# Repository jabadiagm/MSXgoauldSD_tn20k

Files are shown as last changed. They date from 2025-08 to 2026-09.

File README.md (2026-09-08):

# MSXgoauldSD_tn20k
MSX Goa'uld board with Tang Nano 20k and SD support

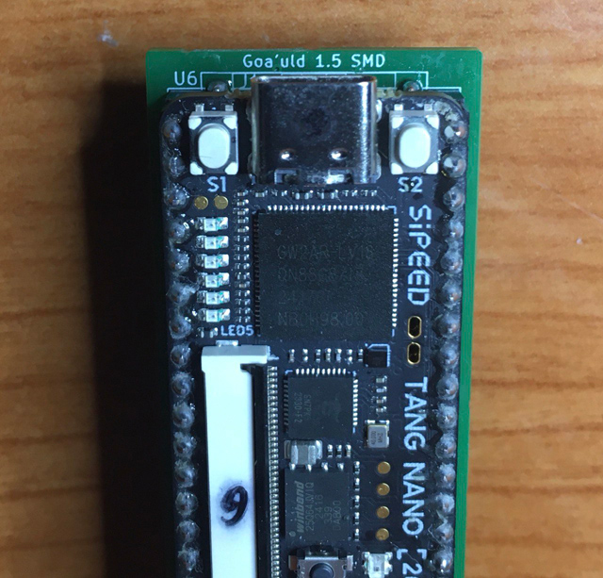
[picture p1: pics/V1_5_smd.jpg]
V1.5_SMD


MSX2+ engine in Z80 socket. It turns one MSX into an MSX2+ by replacing Z80 processor. FPGA in board contains: 
* Z80
* V9958 with hdmi output
* MSX2+ BIOS
* SD Card support + Nextor 2.1
* 4MB mapper
* 2MB megaram SCC
* RTC
* PSG
* OPLL
* Kanji Level 1 & 2
* Wifi support using ESP (experimental)

**For 240p analog video support for consumer CRTs watch DirectVideo branch**

## Boards

Old boards V1.4 and V4.1 are compatible with Goa'uld SD. V3 is not supported, owners of V3 should use Goa'uld standard firmware (0.80).

New pcb V1.5 is same as 1.4, optimized for online PCB assembly. See [Assembly guide](/pcba/pcba.md)

## Slot map

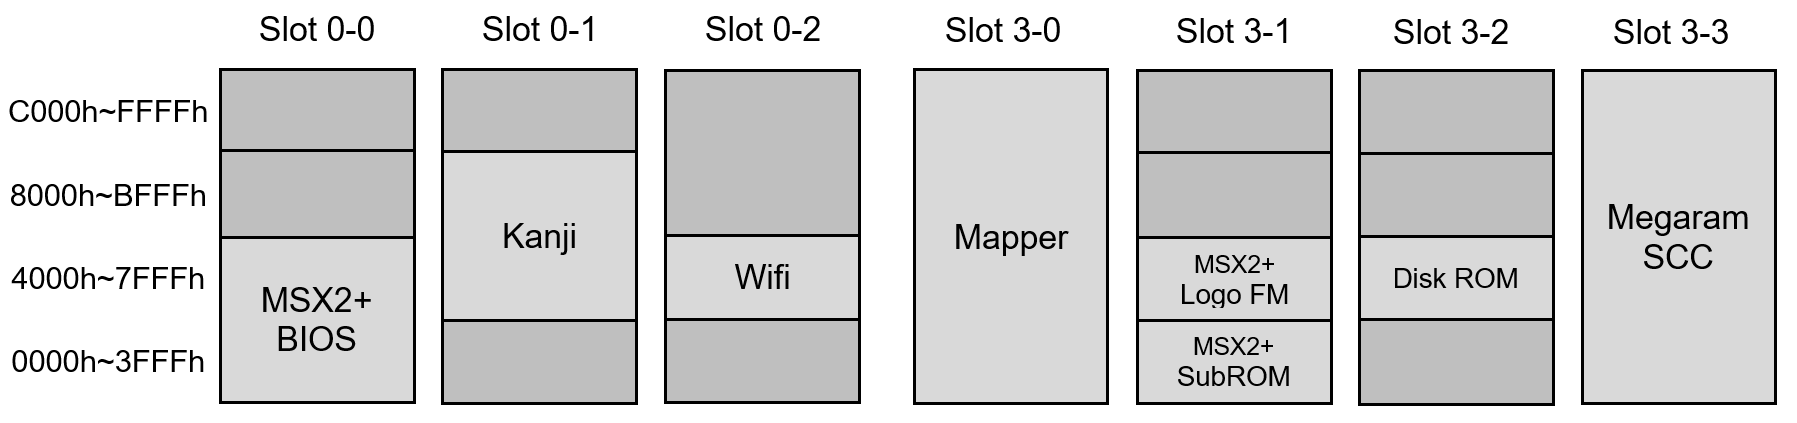
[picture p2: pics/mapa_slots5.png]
Slot map


Mapper and megaram can be relocated to slots 1 or 2 using config menu.

## Megaram + Sofarun
Megaram is detected automatically by sofarun using default settings. When using other software you may need to indicate location, Slot 3-3 by default.

## Configuration
Config menu is showed pressing 'g' during MSX logo. New improved menu is created by [nataliapc](https://github.com/nataliapc/msx_goauld_settings_menu)

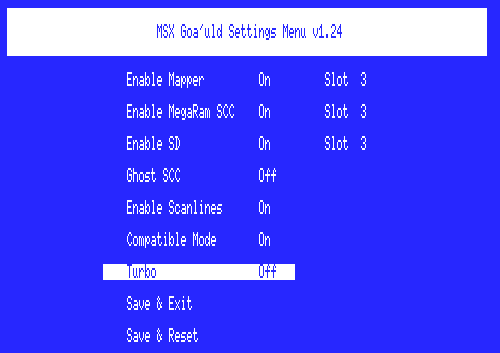
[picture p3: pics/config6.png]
Config


* Enable Mapper: On by default. Disable when having compatibility issues or to use a different mapper
* Enable Megaram: On by default. Disable when having compatibility issues or to use a different megaram
* Enable SD: On by default. Disable when using an external SD mapper
* Mapper Slot: 3 by default. Change to 1 or 2 to get mapper in a not expanded slot. Physical slot will be disabled
* Megaram Slot: 3 by default. Change to 1 or 2 to get megaram in a not expanded slot. Physical slot will be disabled
* Ghost SCC: Off by default. Enable to get sound from an SCC cartridge located in physical slot 1 or 2
* Enable Scanlines: On by default. Disable to get a clean hdmi picture
* Compatible Mode: Off by default. Enable if you experience crashes / unstabilities with external cartridges
* Turbo: Off by default. Enable to use an internal high-speed clock. Recommended for internal SD use only
* Save & Exit: store new config and continue, changes in mapper settings will be effective after pressing reset
* Save & Reset: store new config and make software reset, changes will be immediate

## Known issues
* Reset from config menu is not compatible with some hardware. Use physical reset button when possible
* Tape games fail: use poke -1,0
* Carnivore C2+ and Megaflashrom SCC+ SD are not compatible with Compatible mode (yes, I know)
* Wondertang is not compatible with Turbo mode
* Wifi unreliable: place ESP at appropiate distance from Tang

## Flashing
Programming is done in two steps:
* Flash firmware Z80_goauld.fs  

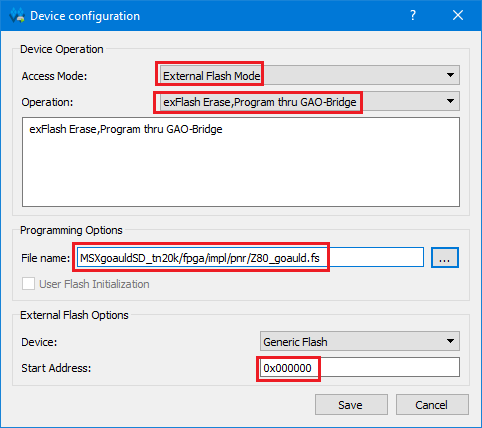
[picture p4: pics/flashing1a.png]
Flash1a

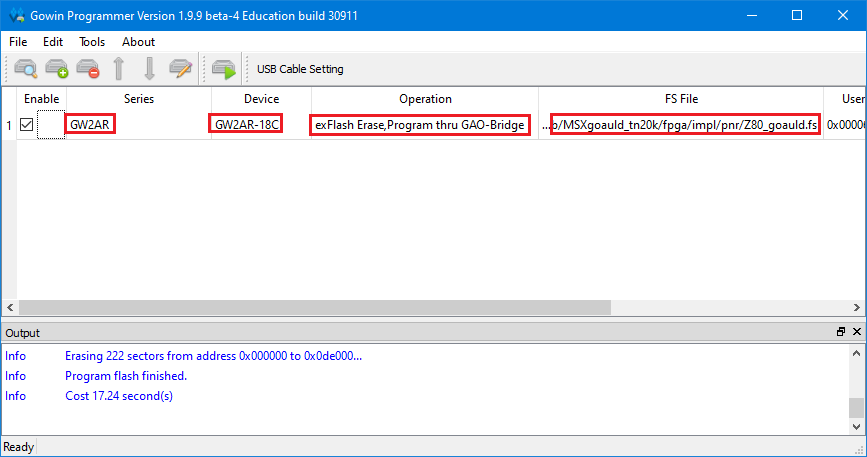
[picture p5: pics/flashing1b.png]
Flash1b

* Flash bios pack. Set Operation = "exFlash C Bin Erase, Program thru GAO-Bridge" and Start Address = 0x200000  

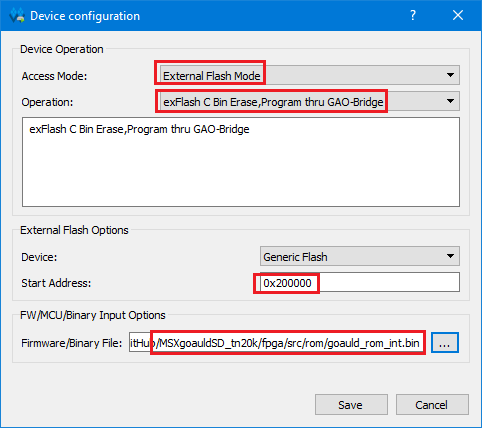
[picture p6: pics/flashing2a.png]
Flash2a

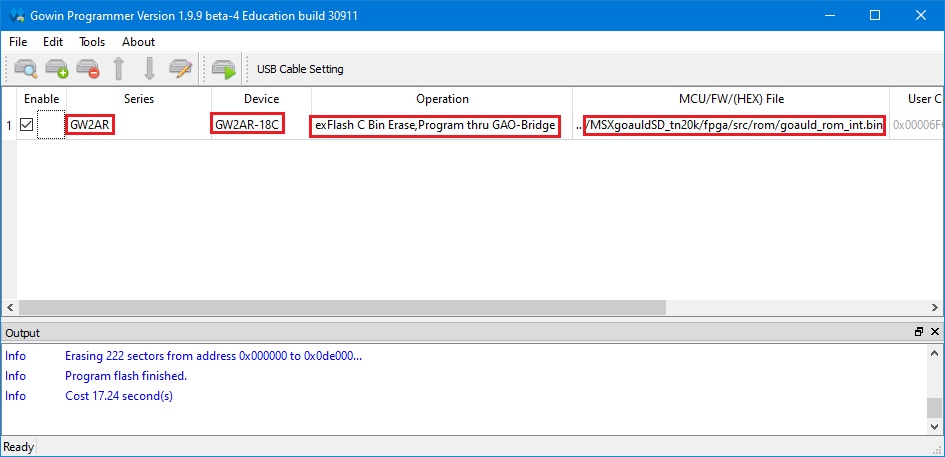
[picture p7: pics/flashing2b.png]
Flash2b


> [!WARNING]
> Not yet fully working on all MSX!
>

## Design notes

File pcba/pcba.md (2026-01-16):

## PCB Assembly guide

Goa'uld board is composed by some smd components and through hole headers. Smd chips are located in the bottom. Using a low profile header for tang is recommended, solder tang to board only when space is too tight.

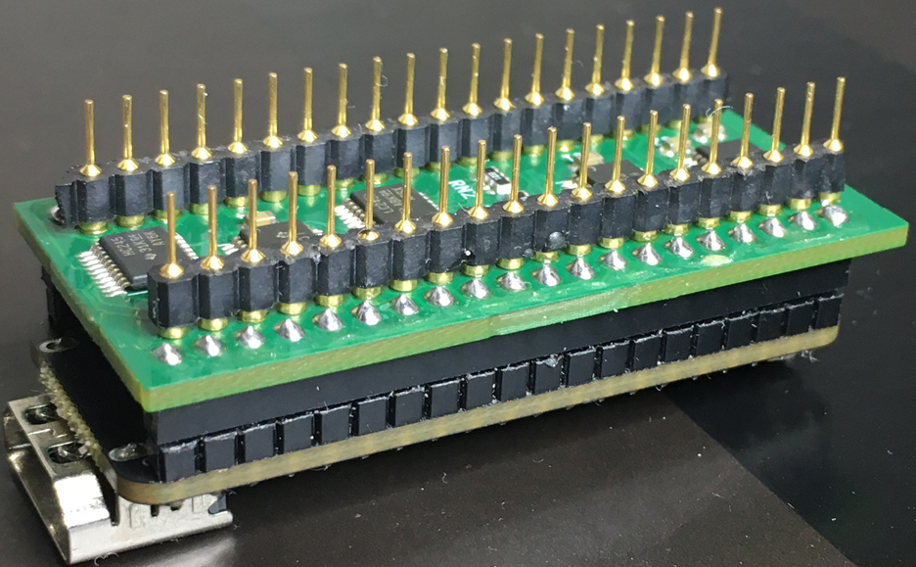
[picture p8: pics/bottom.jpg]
Goa'uld V1.5


Follow these steps to get Goa'uld V1.5 pcb's with smd components assembled using jlcpcb online service

Go to [jlcpcb](https://jlcpcb.com) and select *Add gerber file*

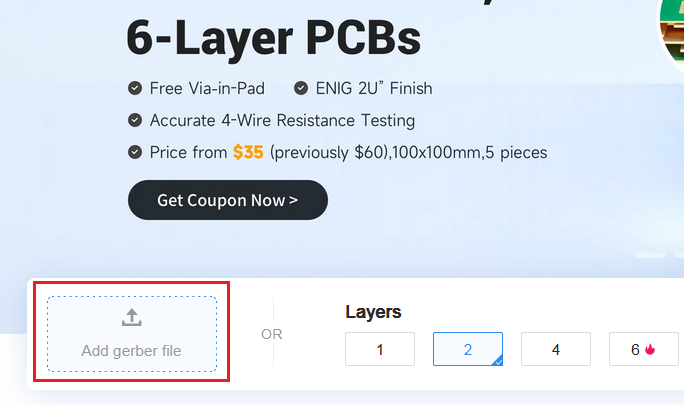
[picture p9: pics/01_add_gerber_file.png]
Add gerber


<br/>

Upload file *gerber.zip*

Upload Gerber

Check gerber is correctly imported

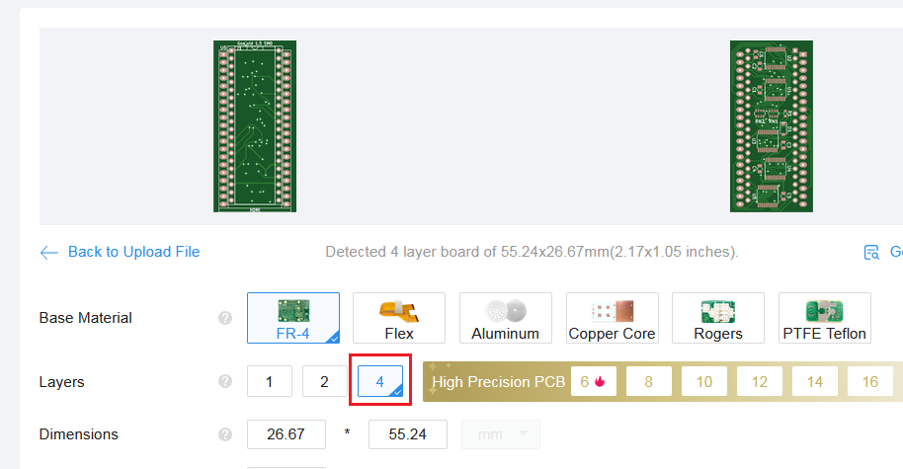
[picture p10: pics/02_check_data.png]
Check gerber


<br/>

Enable PCB Assembly

Enable Assembly

Set following options:
+ *PCBA Type* = *Economic*
+ *Assembly Side* = *Bottom Side*
+ *PCBA Qty* = 5 or 2 (how many assembled boards) 
+ *Confirm Parts Placement* = *Yes*

The latter will get design inspected for correct locations and polarities

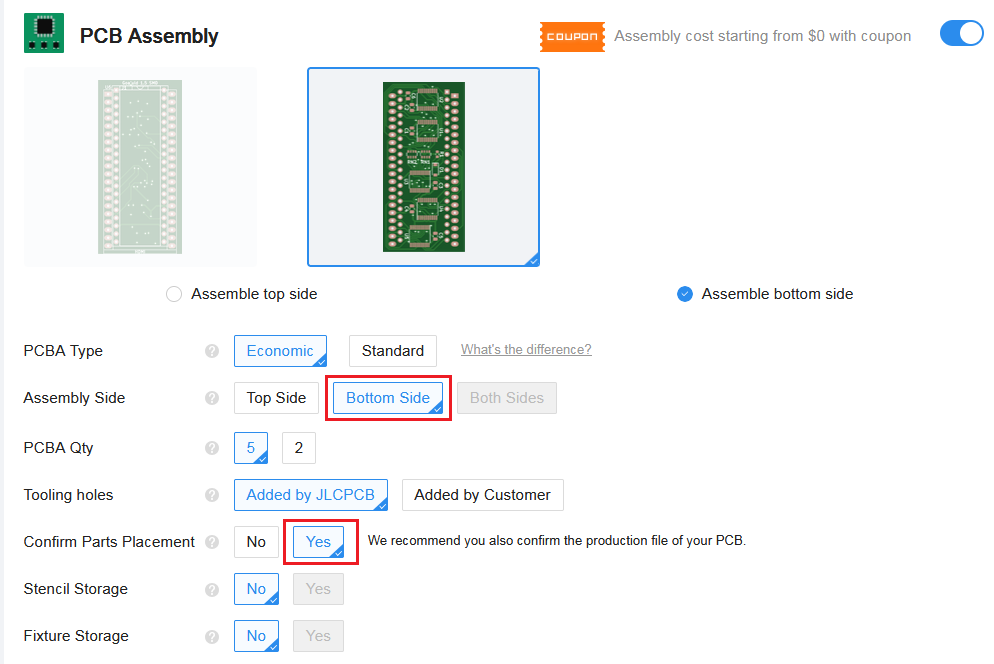
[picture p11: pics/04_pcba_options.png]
pcba options


<br/>

Select *Next*

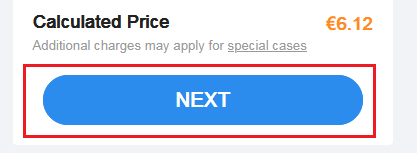
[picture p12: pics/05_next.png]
Next


<br/>

Check pcb layers and select *Next*

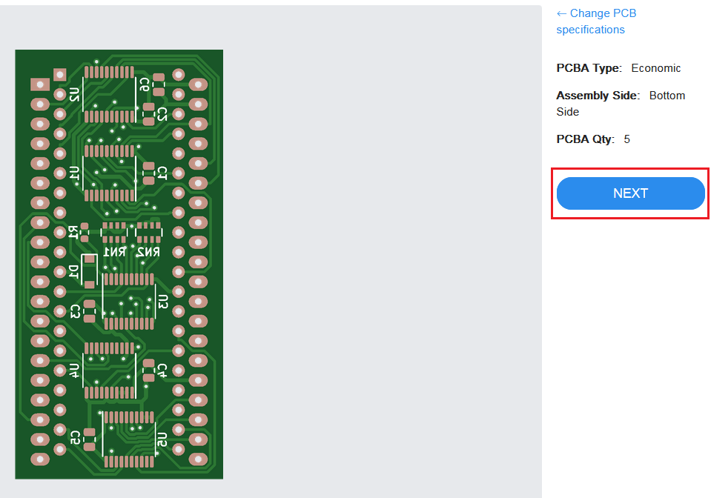
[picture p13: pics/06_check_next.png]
Next


<br/>

Select *Add BOM File*

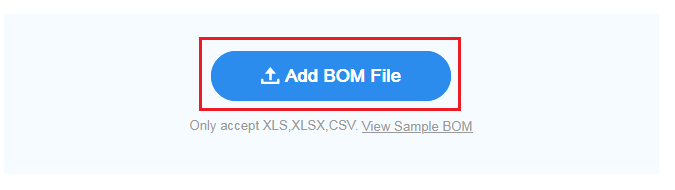
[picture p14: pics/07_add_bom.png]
Add BOM


<br/>

Upload file *bom.csv*

bom.csv

<br/>

Select *Add CPL File*

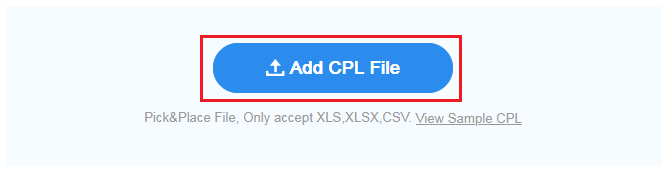
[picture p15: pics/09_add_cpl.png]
Add CPL


<br/>

Upload file *positions.csv*

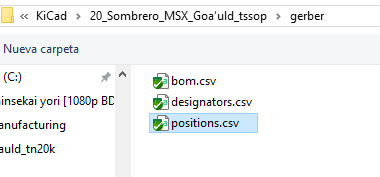
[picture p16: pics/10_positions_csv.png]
positions.csv


<br/>

Select *Process BOM & CPL*

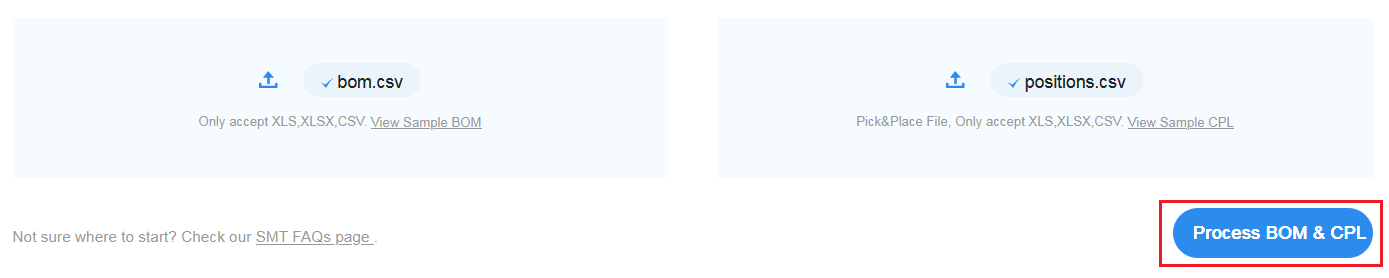
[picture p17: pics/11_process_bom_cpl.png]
Process


<br/>

Leave default values and select *Next*

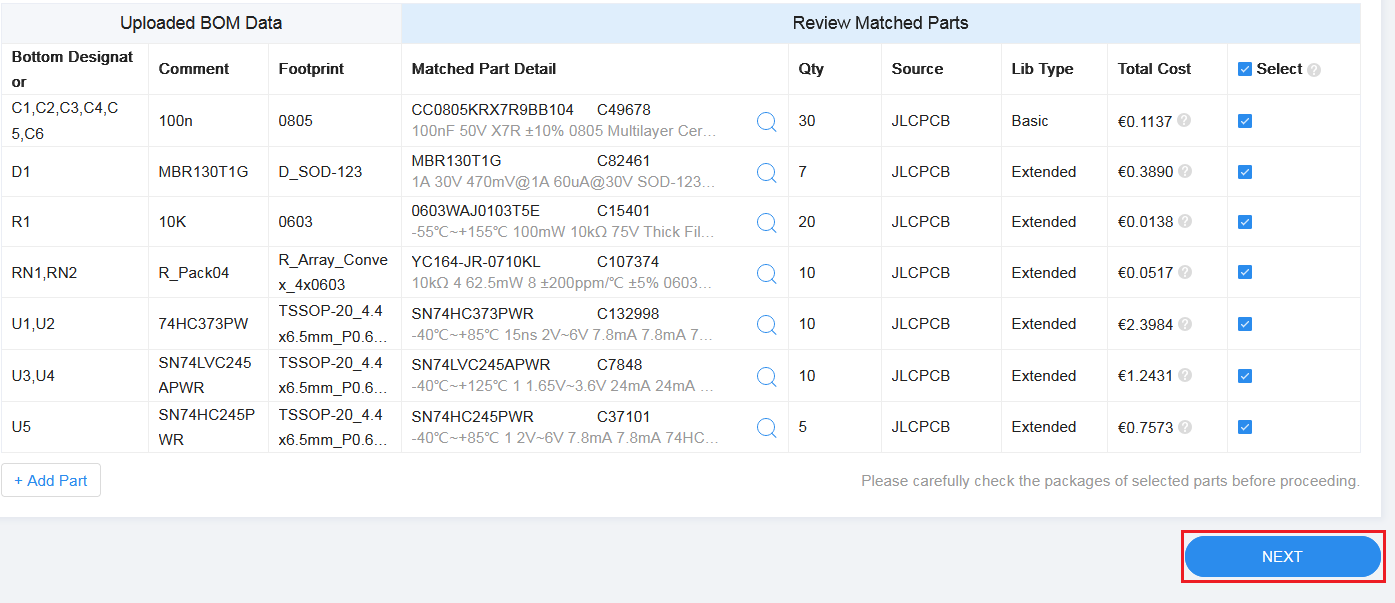
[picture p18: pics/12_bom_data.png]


<br/>

Check positions / polarities and select *Next*

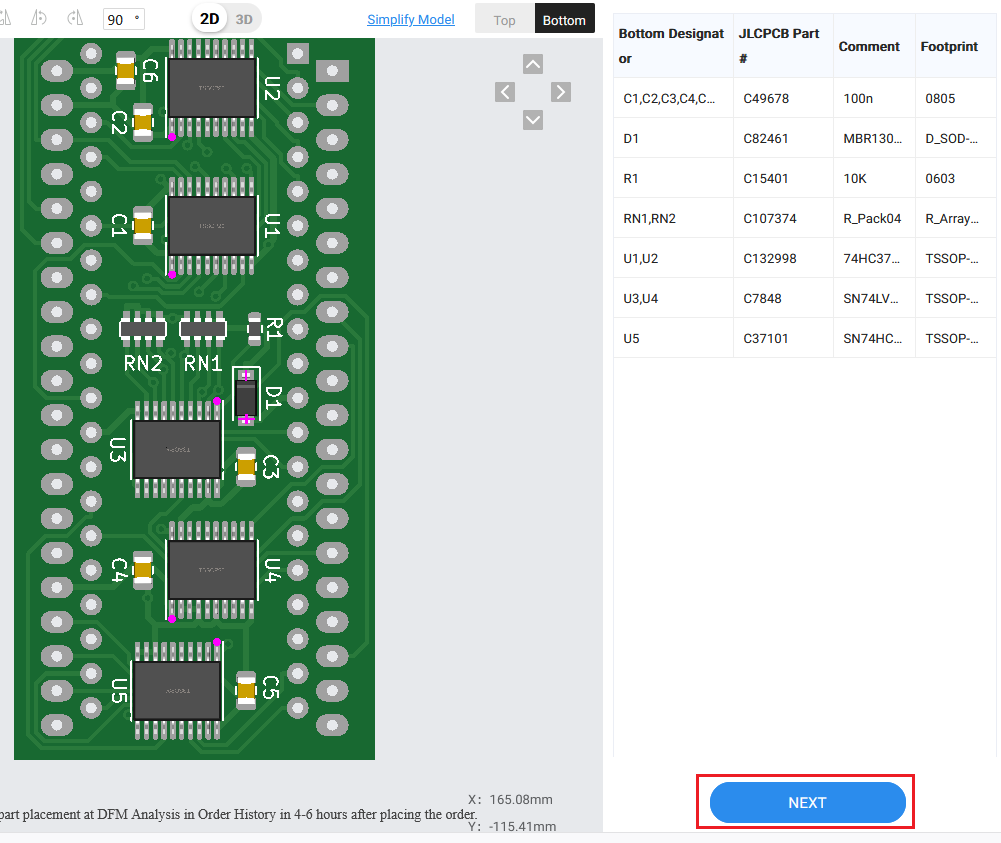
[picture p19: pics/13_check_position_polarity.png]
Check


<br/>

Select and appropiate Product description

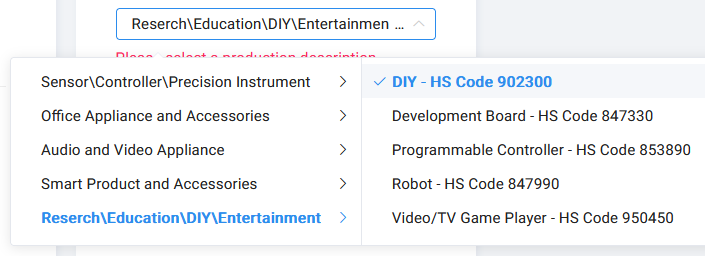
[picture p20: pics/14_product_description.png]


<br/>

Check price and select *SAVE TO CART*

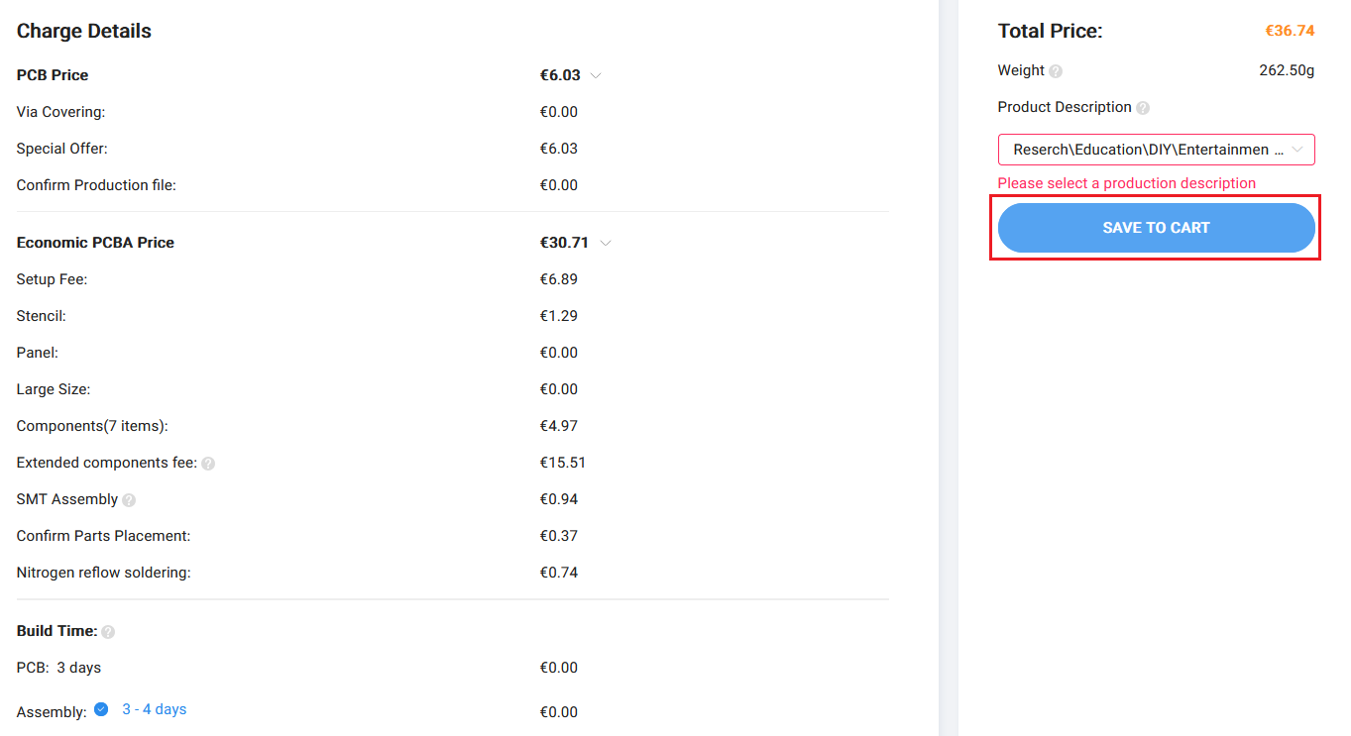
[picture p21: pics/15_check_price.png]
Check price


<br/>

Select all works (pcb manufacturing + pcb assembly) and then *Secure Checkout*

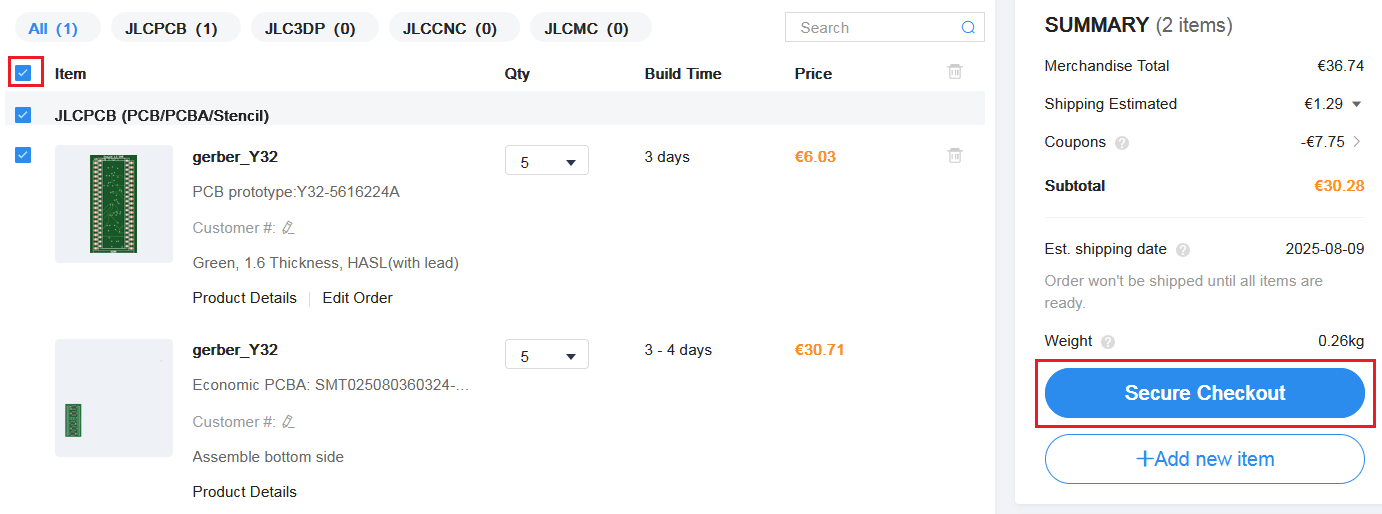
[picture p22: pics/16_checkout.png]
Checkout


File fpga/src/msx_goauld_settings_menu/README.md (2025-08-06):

# MSX Goa'uld Settings Menu

MSX Goa'uld Settings menu for the project: \
https://github.com/jabadiagm/MSXgoauld_tn20k

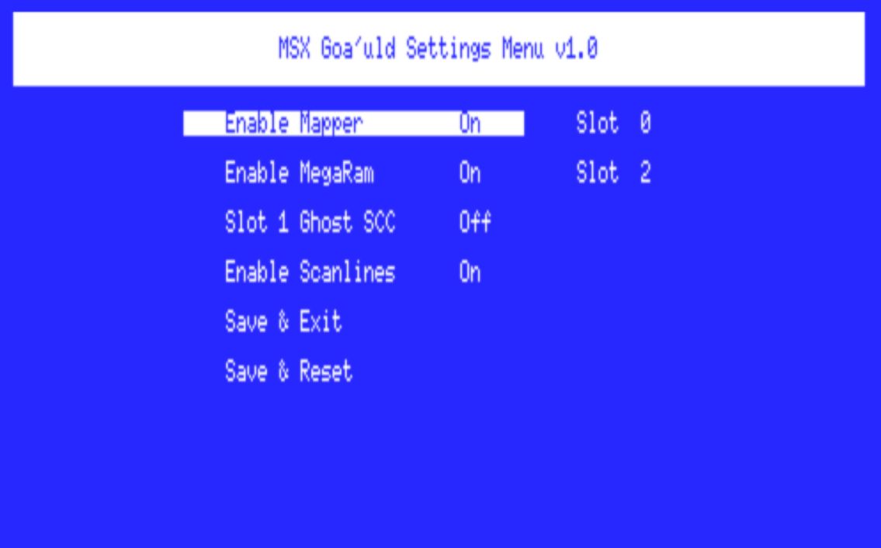
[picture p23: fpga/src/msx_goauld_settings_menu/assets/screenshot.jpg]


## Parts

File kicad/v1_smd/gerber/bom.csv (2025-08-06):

Designator | Footprint | Quantity | Value | LCSC Part #
C1, C2, C3, C4, C5, C6 | 0805 | 6 | 100n | C49678
D1 | D_SOD-123 | 1 | MBR130T1G | C82461
J1 | DIP-40_W15.24mm_Socket | 1 | Z80CPU
R1 | 0603 | 1 | 10K | C15401
RN1, RN2 | R_Array_Convex_4x0603 | 2 | R_Pack04 | C107374
U1, U2 | TSSOP-20_4.4x6.5mm_P0.65mm | 2 | 74HC373PW | C132998
U3, U4 | TSSOP-20_4.4x6.5mm_P0.65mm | 2 | SN74LVC245APWR | C7848
U5 | TSSOP-20_4.4x6.5mm_P0.65mm | 1 | SN74HC245PWR | C37101
U6 | Tang_Nano_20k | 1 | Tang_Nano_20k

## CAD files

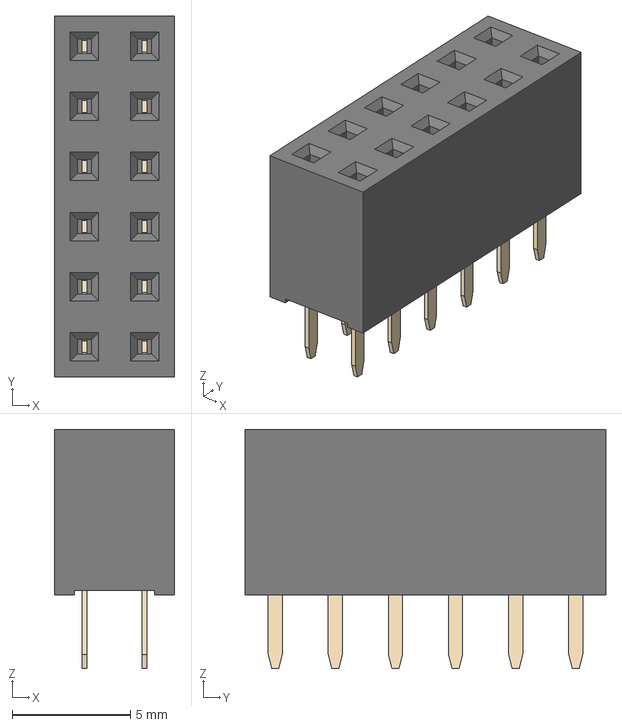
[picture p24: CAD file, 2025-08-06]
kicad/v1_smd/librerias/3D/PinSocket_2x06_P2.54mm_Vertical.step
5.08 x 15.2 x 10.1 mm

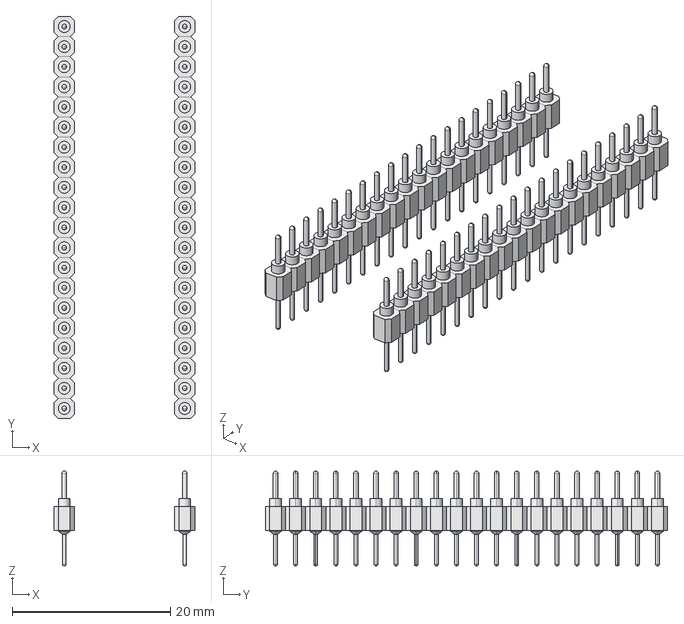
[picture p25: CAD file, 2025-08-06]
kicad/v1_smd/librerias/3D/Z80_PINHEADER.step
17.8 x 50.8 x 12.0 mm
Header-Male-round x 40

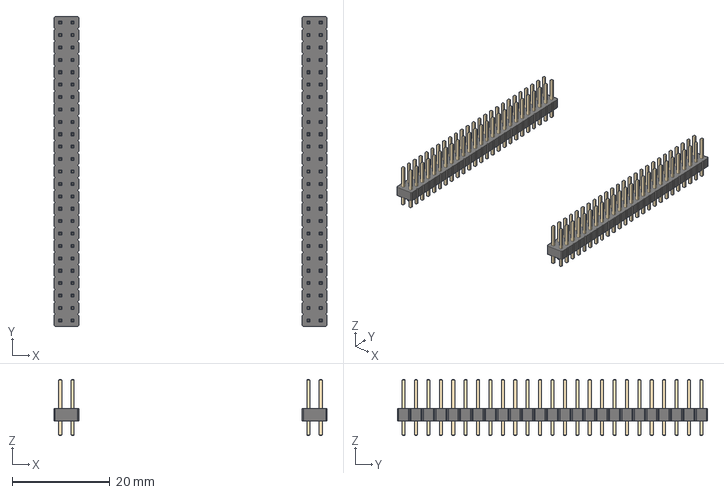
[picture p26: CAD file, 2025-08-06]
kicad/v1_smd/librerias/3D/Qmtech_xc7a15t_35t.step
55.9 x 63.5 x 11.5 mm
PinHeader_2x25_P254mm_Vertical x 2

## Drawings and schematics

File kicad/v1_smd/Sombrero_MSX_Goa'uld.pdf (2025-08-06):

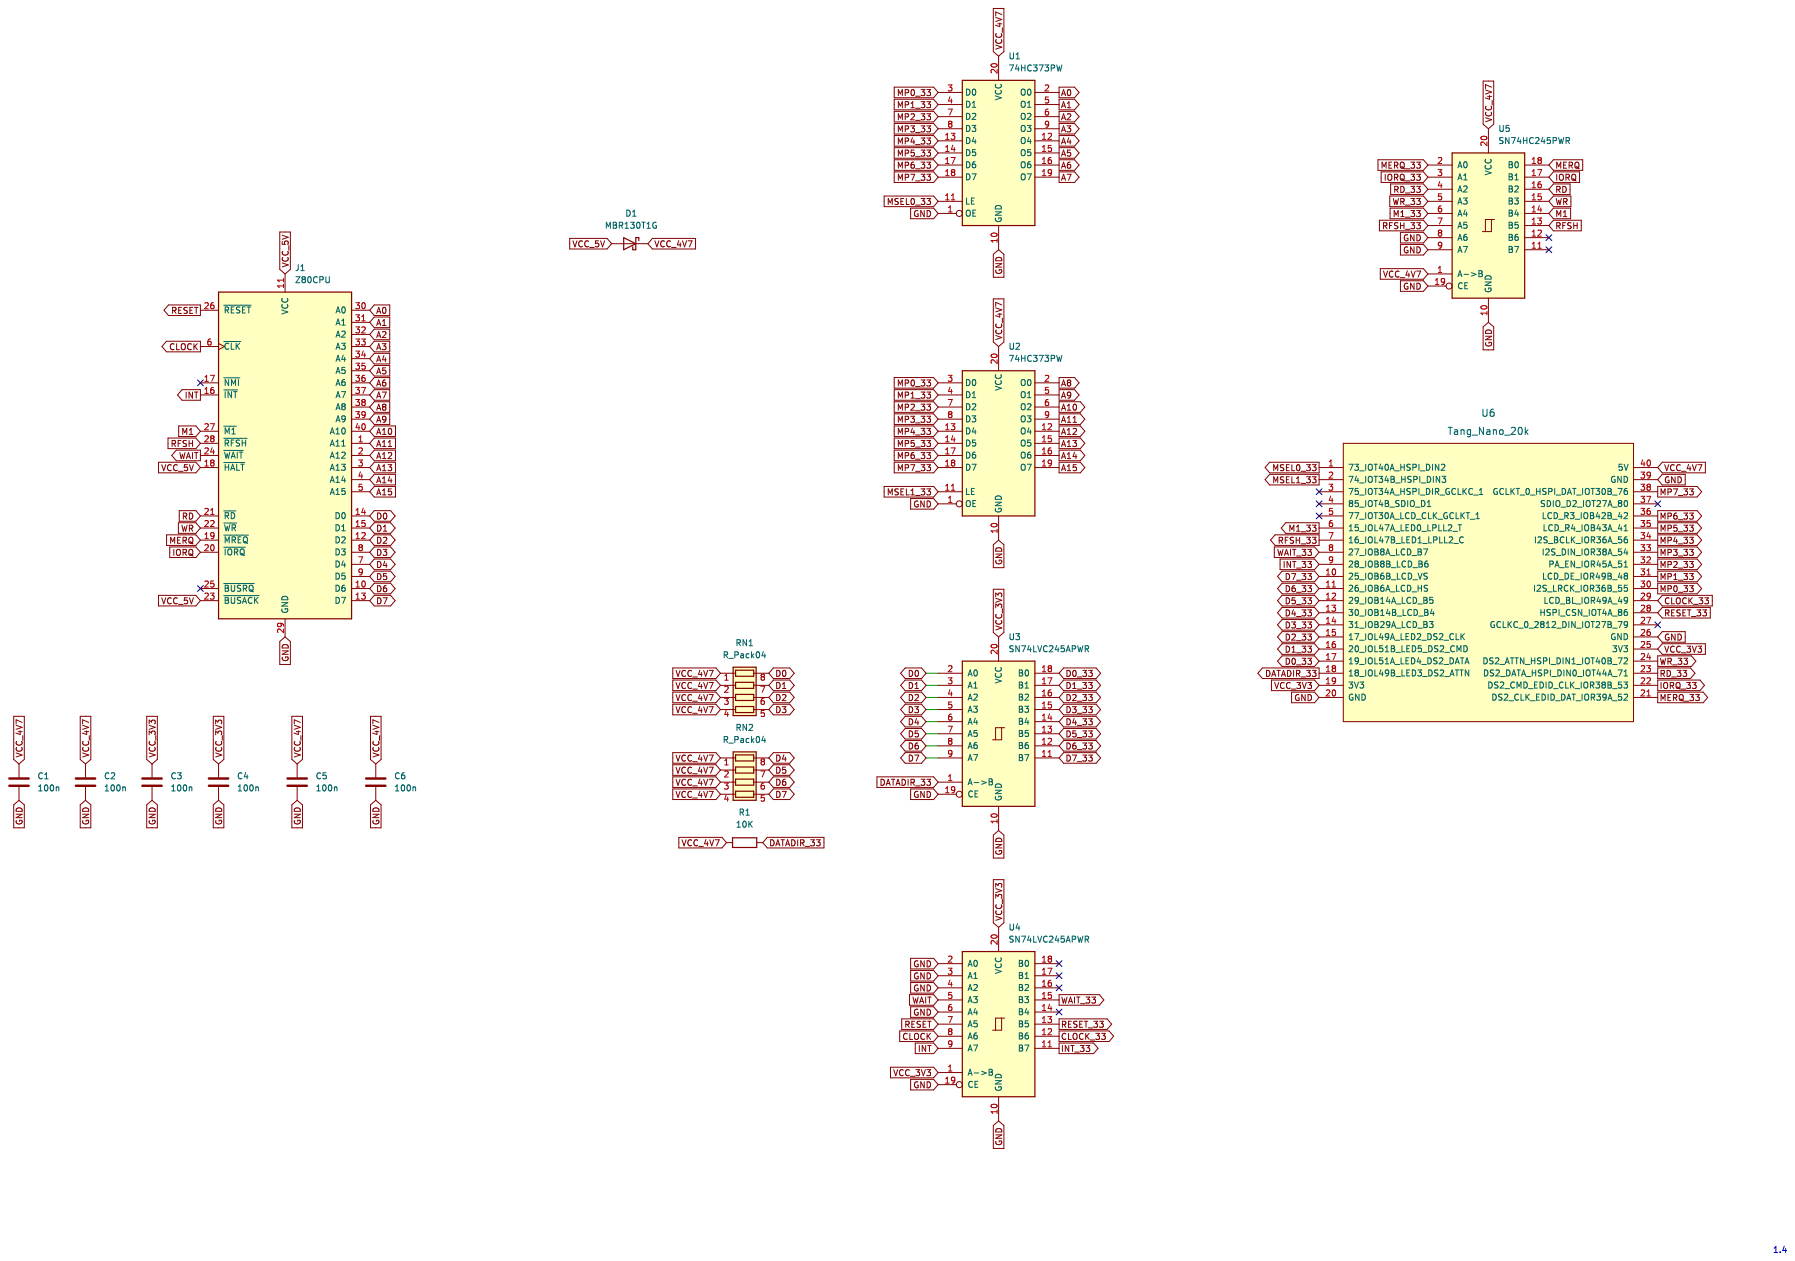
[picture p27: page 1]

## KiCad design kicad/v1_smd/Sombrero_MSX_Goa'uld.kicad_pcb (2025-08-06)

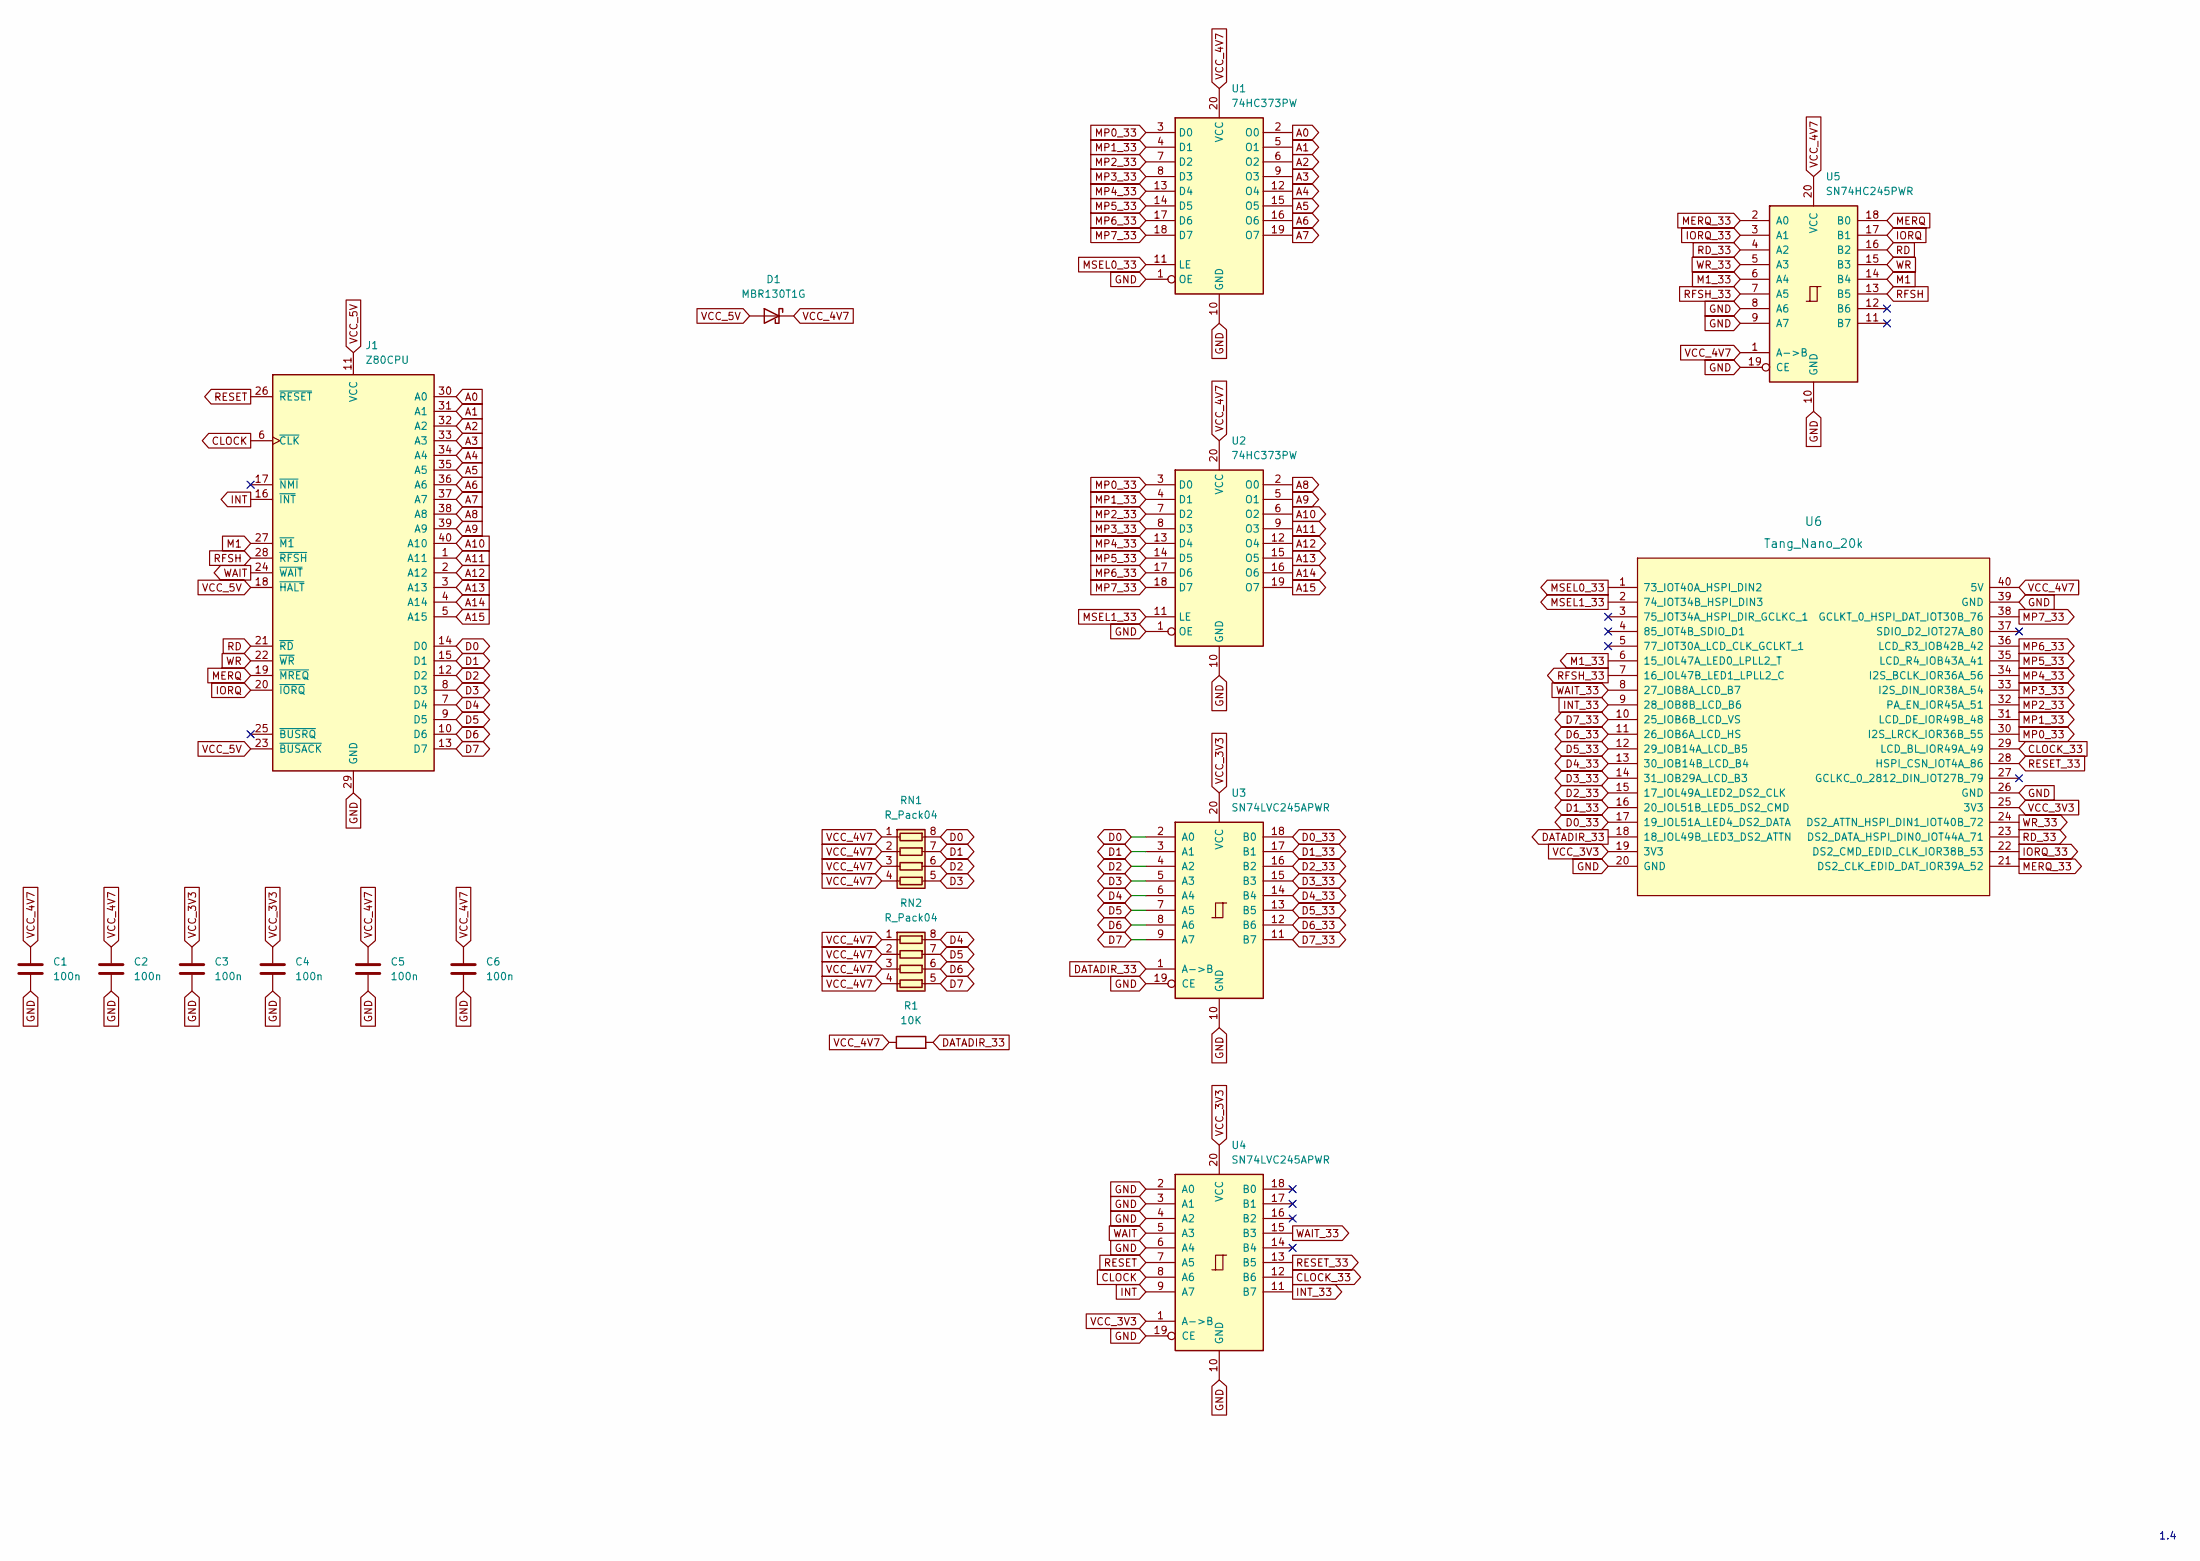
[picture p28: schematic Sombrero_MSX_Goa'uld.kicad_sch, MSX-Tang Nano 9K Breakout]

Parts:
C1, C2, C3, C4, C5, C6: 100n; C_0805_2012Metric; LCSC C49678
D1: MBR130T1G; D_SOD-123; LCSC C82461
J1: Z80CPU; DIP-40_W15.24mm_Socket
R1: 10K; R_0603_1608Metric; LCSC C15401
RN1, RN2: R_Pack04; R_Array_Convex_4x0603; LCSC C107374
U1, U2: 74HC373PW; TSSOP-20_4.4x6.5mm_P0.65mm; LCSC C132998
U3, U4: SN74LVC245APWR; TSSOP-20_4.4x6.5mm_P0.65mm; LCSC C7848
U5: SN74HC245PWR; TSSOP-20_4.4x6.5mm_P0.65mm; LCSC C37101
U6: Tang_Nano_20k

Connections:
A0: J1.30 (A0), U1.2 (O0)
A1: J1.31 (A1), U1.5 (O1)
A2: J1.32 (A2), U1.6 (O2)
A3: J1.33 (A3), U1.9 (O3)
A4: J1.34 (A4), U1.12 (O4)
A5: J1.35 (A5), U1.15 (O5)
A6: J1.36 (A6), U1.16 (O6)
A7: J1.37 (A7), U1.19 (O7)
A8: J1.38 (A8), U2.2 (O0)
A9: J1.39 (A9), U2.5 (O1)
A10: J1.40 (A10), U2.6 (O2)
A11: J1.1 (A11), U2.9 (O3)
A12: J1.2 (A12), U2.12 (O4)
A13: J1.3 (A13), U2.15 (O5)
A14: J1.4 (A14), U2.16 (O6)
A15: J1.5 (A15), U2.19 (O7)
CLOCK: J1.6 (~CLK), U4.8 (A6)
CLOCK_33: U4.12 (B6), U6.29 (LCD_BL_IOR49A_49)
D0: J1.14 (D0), RN1.8 (R1.2), U3.2 (A0)
D0_33: U3.18 (B0), U6.17 (19_IOL51A_LED4_DS2_DATA)
D1: J1.15 (D1), RN1.7 (R2.2), U3.3 (A1)
D1_33: U3.17 (B1), U6.16 (20_IOL51B_LED5_DS2_CMD)
D2: J1.12 (D2), RN1.6 (R3.2), U3.4 (A2)
D2_33: U3.16 (B2), U6.15 (17_IOL49A_LED2_DS2_CLK)
D3: J1.8 (D3), RN1.5 (R4.2), U3.5 (A3)
D3_33: U3.15 (B3), U6.14 (31_IOB29A_LCD_B3)
D4: J1.7 (D4), RN2.8 (R1.2), U3.6 (A4)
D4_33: U3.14 (B4), U6.13 (30_IOB14B_LCD_B4)
D5: J1.9 (D5), RN2.7 (R2.2), U3.7 (A5)
D5_33: U3.13 (B5), U6.12 (29_IOB14A_LCD_B5)
D6: J1.10 (D6), RN2.6 (R3.2), U3.8 (A6)
D6_33: U3.12 (B6), U6.11 (26_IOB6A_LCD_HS)
D7: J1.13 (D7), RN2.5 (R4.2), U3.9 (A7)
D7_33: U3.11 (B7), U6.10 (25_IOB6B_LCD_VS)
DATADIR_33: R1.2, U3.1 (A->B), U6.18 (18_IOL49B_LED3_DS2_ATTN)
GND: C1.2, C2.2, C3.2, C4.2, C5.2, C6.2, J1.29 (GND), U1.1 (OE), U1.10 (GND), U2.1 (OE), U2.10 (GND), U3.10 (GND), U3.19 (CE), U4.2 (A0), U4.3 (A1), U4.4 (A2), U4.6 (A4), U4.10 (GND), U4.19 (CE), U5.8 (A6), U5.9 (A7), U5.10 (GND), U5.19 (CE), U6.20 (GND), U6.26 (GND), U6.39 (GND)
INT: J1.16 (~INT), U4.9 (A7)
INT_33: U4.11 (B7), U6.9 (28_IOB8B_LCD_B6)
IORQ: J1.20 (~IORQ), U5.17 (B1)
IORQ_33: U5.3 (A1), U6.22 (DS2_CMD_EDID_CLK_IOR38B_53)
M1: J1.27 (~M1), U5.14 (B4)
M1_33: U5.6 (A4), U6.6 (15_IOL47A_LED0_LPLL2_T)
MERQ: J1.19 (~MREQ), U5.18 (B0)
MERQ_33: U5.2 (A0), U6.21 (DS2_CLK_EDID_DAT_IOR39A_52)
MP0_33: U1.3 (D0), U2.3 (D0), U6.30 (I2S_LRCK_IOR36B_55)
MP1_33: U1.4 (D1), U2.4 (D1), U6.31 (LCD_DE_IOR49B_48)
MP2_33: U1.7 (D2), U2.7 (D2), U6.32 (PA_EN_IOR45A_51)
MP3_33: U1.8 (D3), U2.8 (D3), U6.33 (I2S_DIN_IOR38A_54)
MP4_33: U1.13 (D4), U2.13 (D4), U6.34 (I2S_BCLK_IOR36A_56)
MP5_33: U1.14 (D5), U2.14 (D5), U6.35 (LCD_R4_IOB43A_41)
MP6_33: U1.17 (D6), U2.17 (D6), U6.36 (LCD_R3_IOB42B_42)
MP7_33: U1.18 (D7), U2.18 (D7), U6.38 (GCLKT_0_HSPI_DAT_IOT30B_76)
MSEL0_33: U1.11 (LE), U6.1 (73_IOT40A_HSPI_DIN2)
MSEL1_33: U2.11 (LE), U6.2 (74_IOT34B_HSPI_DIN3)
RD: J1.21 (~RD), U5.16 (B2)
RD_33: U5.4 (A2), U6.23 (DS2_DATA_HSPI_DIN0_IOT44A_71)
RESET: J1.26 (~RESET), U4.7 (A5)
RESET_33: U4.13 (B5), U6.28 (HSPI_CSN_IOT4A_86)
RFSH: J1.28 (~RFSH), U5.13 (B5)
RFSH_33: U5.7 (A5), U6.7 (16_IOL47B_LED1_LPLL2_C)
VCC_3V3: C3.1, C4.1, U3.20 (VCC), U4.1 (A->B), U4.20 (VCC), U6.19 (3V3), U6.25 (3V3)
VCC_4V7: C1.1, C2.1, C5.1, C6.1, D1.1 (K), R1.1, RN1.1 (R1.1), RN1.2 (R2.1), RN1.3 (R3.1), RN1.4 (R4.1), RN2.1 (R1.1), RN2.2 (R2.1), RN2.3 (R3.1), RN2.4 (R4.1), U1.20 (VCC), U2.20 (VCC), U5.1 (A->B), U5.20 (VCC), U6.40 (5V)
VCC_5V: D1.2 (A), J1.11 (VCC), J1.18 (~HALT), J1.23 (~BUSACK)
WAIT: J1.24 (~WAIT), U4.5 (A3)
WAIT_33: U4.15 (B3), U6.8 (27_IOB8A_LCD_B7)
WR: J1.22 (~WR), U5.15 (B3)
WR_33: U5.5 (A3), U6.24 (DS2_ATTN_HSPI_DIN1_IOT40B_72)

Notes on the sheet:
1.4

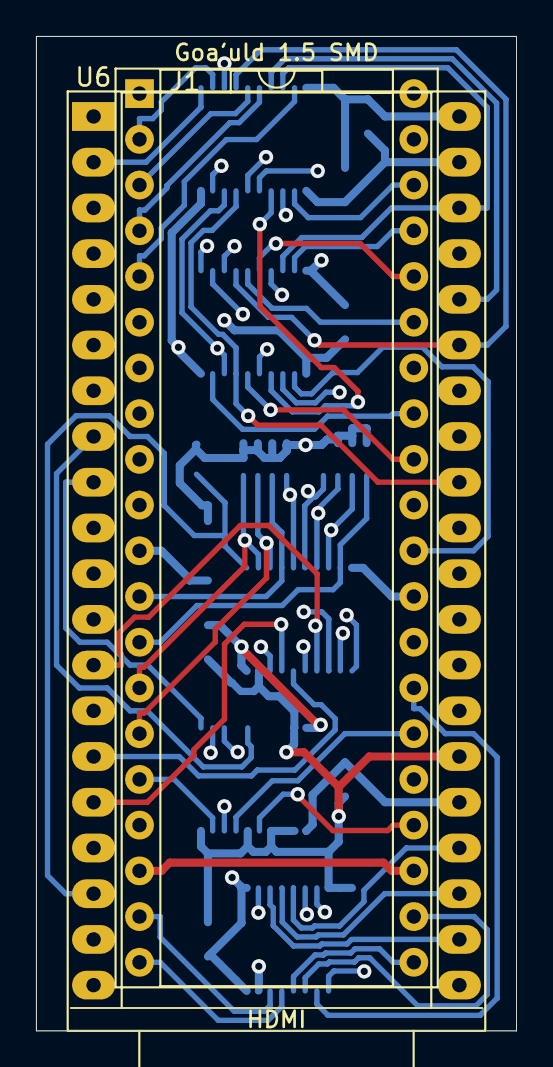
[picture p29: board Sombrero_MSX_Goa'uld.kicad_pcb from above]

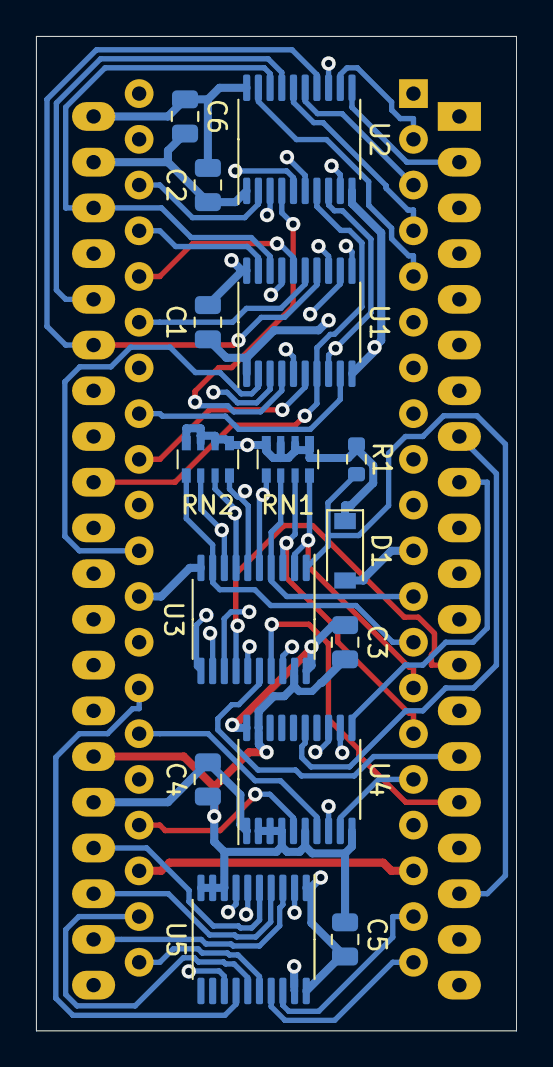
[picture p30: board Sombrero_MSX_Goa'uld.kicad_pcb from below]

Board: 4 copper layers, 26.7 x 55.2 mm, 17 parts (15 on the bottom side), 67 nets.

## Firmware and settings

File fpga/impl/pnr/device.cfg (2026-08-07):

set JTAG regular_io = false
set SSPI regular_io = true
set MSPI regular_io = true
set READY regular_io = false
set DONE regular_io = false
set I2C regular_io = false
set RECONFIG_N regular_io = false
set CRC_check = true
set compress = false
set encryption = false
set security_bit_enable = true
set bsram_init_fuse_print = true
set background_programming = off
set secure_mode = false
set download_speed = 250/32
set program_done_bypass = false
set wake_up = 0
set format = binary
set power_on_reset_monitor = true
set multiboot_spi_flash_address = 0x00000000
set vccx = 3.3
set vcc = 1.0
set unused_pin = default

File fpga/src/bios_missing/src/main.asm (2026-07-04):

.ZILOG
.BIOS
.BIOSVARS

.org #0000

; ############## Initialization

bios_missing:
	di
	in   a, (#99)				; resetea el latch de registro/direccion del VDP

	; --- Programa R0..R7 del VDP para TEXT1 (SCREEN 0), pantalla apagada ---
	ld   hl, vdp_init_tab
	ld   c, 0
.reg_loop:
	ld   a, (hl)
	inc  hl
	out  (#99), a				; dato del registro
	ld   a, c
	or   #80
	out  (#99), a				; 0x80 | nº de registro
	inc  c
	ld   a, c
	cp   8
	jr   nz, .reg_loop

	; --- Carga las 8 glifos en la tabla de patrones @ 0x0800 ---
	ld   a, #00					; direccion VRAM = 0x0800, modo escritura
	out  (#99), a
	ld   a, #48					; 0x40 (write) | 0x08 (byte alto)
	out  (#99), a
	ld   hl, font_data
	ld   b, 8*8					; 8 glifos x 8 bytes
.font_loop:
	ld   a, (hl)
	out  (#98), a
	inc  hl
	djnz .font_loop

	; --- Limpia la tabla de nombres (40x24 = 960) con el glifo 0 (espacio) ---
	xor  a						; direccion VRAM = 0x0000, modo escritura
	out  (#99), a
	ld   a, #40
	out  (#99), a
	ld   bc, 960
.clear_loop:
	xor  a
	out  (#98), a
	dec  bc
	ld   a, b
	or   c
	jr   nz, .clear_loop

	; --- Escribe "Bios Missing" centrado (fila 11, col 14 -> 0x01C6) ---
	ld   a, #C6
	out  (#99), a
	ld   a, #41					; 0x40 (write) | 0x01 (byte alto)
	out  (#99), a
	ld   hl, msg
	ld   b, msg_len
.msg_loop:
	ld   a, (hl)
	out  (#98), a
	inc  hl
	djnz .msg_loop

	; --- Enciende la pantalla (R1 bit6) ---
	ld   a, #D0					; 16K + display ON + M1 (text)
	out  (#99), a
	ld   a, #81					; 0x80 | 1
	out  (#99), a

.hang:
	jr   .hang

; R0..R7 (R1 con display OFF; se enciende tras cargar la VRAM)
vdp_init_tab:
	.db #00		; R0: TEXT1
	.db #90		; R1: 16K + M1 (text), display OFF
	.db #00		; R2: tabla de nombres @ 0x0000
	.db #00		; R3: (tabla de color, no usada en TEXT1)
	.db #01		; R4: generador de patrones @ 0x0800
	.db #00		; R5: (atrib. sprites, no usado)
	.db #00		; R6: (gen. sprites, no usado)
	.db #F2		; R7: texto blanco (F) sobre el fondo actual (indice 2 = tu rojo)

; Indices de glifo: 0=espacio 1=B 2=i 3=o 4=s 5=M 6=n 7=g
msg:
	.db 1,2,3,4, 0, 5,2,4,4,2,6,7	; "Bios Missing"
msg_len equ 12

; Fuente 8x8 (bit7 = pixel izquierdo)
font_data:
	.db #00,#00,#00,#00,#00,#00,#00,#00	; 0 espacio
	.db #F8,#84,#84,#F8,#84,#84,#F8,#00	; 1 B
	.db #10,#00,#10,#10,#10,#10,#10,#00	; 2 i
	.db #00,#00,#78,#84,#84,#84,#78,#00	; 3 o
	.db #00,#00,#7C,#80,#78,#04,#F8,#00	; 4 s
	.db #84,#CC,#AC,#84,#84,#84,#84,#00	; 5 M  (6px: barra dcha en bit2, no bit1)
	.db #00,#00,#B8,#C4,#84,#84,#84,#00	; 6 n
	.db #00,#00,#7C,#84,#84,#7C,#04,#78	; 7 g

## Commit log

2025-08-06 Version FW 0.90 *Updated logic, sdram controller *Updated logic, included sdcard support *Updated logic, _req signals sync *Updated logic, psg noise filter *Removed module, scc+ fixed problem channel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
    [PinSocket_2x06_P2.54mm_Vertical.step, Qmtech_xc7a15t_35t.step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]
2025-08-06 Updated readme, included pcba guide
2025-08-06 updated pcba
2025-08-29 Version FW 0.91 *Updated logic, slots map *Updated menu *Updated logic, boot menu before logo *Updated logic, main logic at 54 MHz *Include directive, swap slots 2,3
    [memory.v, top.v]
2026-01-24 Version FW 0.92 *Removed option SDRAM_32 *Updated logic memory_ctrl *Updated logic, rom loaded into sdram during boot *Fixed bug rtc *Updated logic, slot 0 expanded *Updated logic, included waitstate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
    [flash_rw.v, memory.v, top.v]
2026-07-04 Version FW 0.93 *Updated logic, main logic at 54 MHz *Included option Turbo 6.75 MHz *Fixed bug wait_n during writing *Updated logic, fixed option ENABLE_V9958 *Updated logic, wait cycles *Updated me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
    [main.asm, memory.v]
2026-08-07 Version FW 0.94 *Fixed bug, DRIVE *Replaced module, jtopl -> ikaopll *Replaced module, tn_vdp -> V9968L *Replaced module, psg_filter -> lpf_butter4_8k *Updated logic, ENABLE_CUSTOM_ROM *Updated logic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
    [device.cfg]
2026-09-25 Version FW 0.95 *Fixed bug, bus isolation *Updated logic, joystick in boot menu
    [top.v]

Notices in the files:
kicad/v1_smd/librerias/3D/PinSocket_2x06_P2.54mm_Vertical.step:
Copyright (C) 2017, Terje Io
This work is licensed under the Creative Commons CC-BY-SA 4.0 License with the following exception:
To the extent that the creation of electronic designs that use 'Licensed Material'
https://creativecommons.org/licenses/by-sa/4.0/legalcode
